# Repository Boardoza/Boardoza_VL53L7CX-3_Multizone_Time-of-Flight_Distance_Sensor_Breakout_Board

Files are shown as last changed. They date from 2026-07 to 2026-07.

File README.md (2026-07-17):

# Boardoza VL53L7CX-3 Time-of-Flight Breakout Board

The **Boardoza VL53L7CX-3 Time-of-Flight Breakout Board** is a compact distance sensing solution built around the **STMicroelectronics VL53L7CX** multizone Time-of-Flight (ToF) sensor. The sensor combines a **940 nm invisible VCSEL emitter** and a **SPAD receiving array** to deliver accurate distance measurements across a configurable **4×4 or 8×8 ranging zone matrix**, providing up to **64 independent zones**.

Designed specifically for **3.3V to 5V powered systems**, this breakout board integrates a low-dropout voltage regulator and level-shifting circuitry for I²C communication and interrupt signaling.This enables direct connection to both 3.3V and 5V microcontroller systems while providing the required operating voltage for the sensor. The board also provides extra control functions such as interrupt output (INT), communication enable control (LPn), and I²C interface reset (RST). Its dual-connector layout also allows multiple boards to be connected in a **cascade connection**, making it easier to use more than one VL53L7CX board on the same I²C bus. Typical applications include **robotics, occupancy detection, gesture recognition, obstacle avoidance, smart appliances, industrial automation, and embedded sensing applications** where compact size and reliable ranging performance are required.

## [Click here to purchase!](https://www.ozdisan.com/p/moduller-870/boardoza-vl53l7cx-3-1577677?s=VL53L7CX-3)

| Front Side | Back Side |
| :---: | :---: |
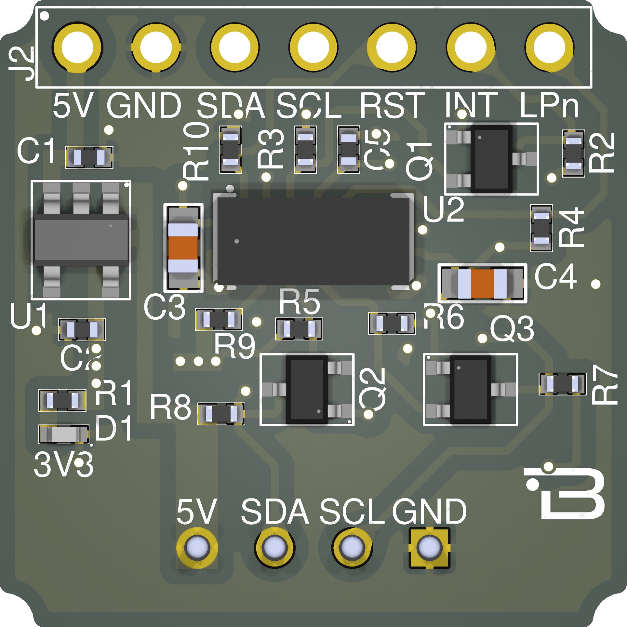
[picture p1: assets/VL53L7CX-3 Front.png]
Front
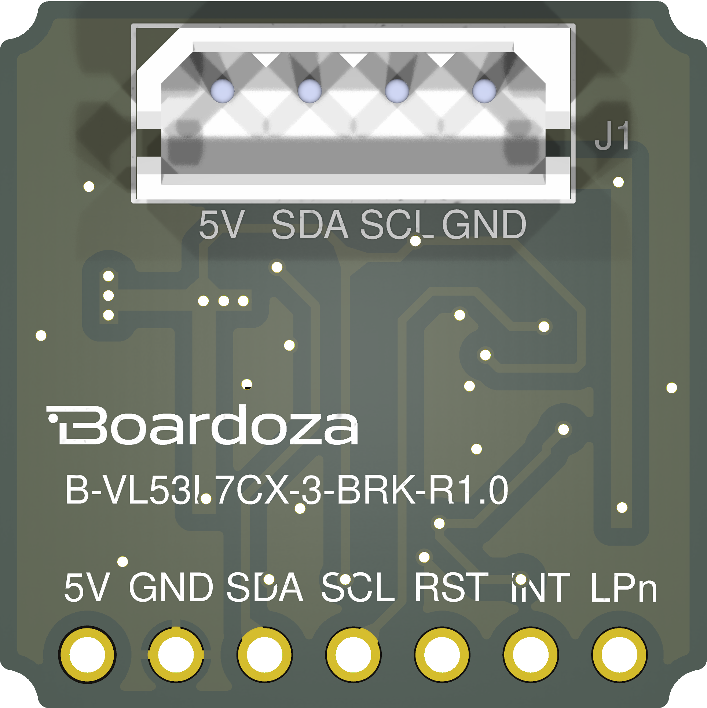
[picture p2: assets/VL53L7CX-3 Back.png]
Back
|  |  |

---

## Key Features

- **Multizone Distance Sensing:** Supports both 4×4 and 8×8 ranging configurations, providing up to 64 independent measurement zones.
- **Ultra-Wide Field of View:** Provides a 60° × 60° square detection FoV with a 90° diagonal field of view.
- **3.3V–5V System Compatible:** Supports a 3.3V to 5V supply input with onboard voltage regulation.
- **Level-Shifted Communication and Interrupt Lines:** SDA, SCL, and INT lines include level shifting for compatibility with 3.3V and 5V microcontroller systems.
- **3.3V Control Signals:** RST and LPn pins operate at 3.3V logic level and should not be driven with 5V signals.
- **Eye-Safe Operation:** Integrated Class 1 invisible 940nm VCSEL (Vertical-Cavity Surface-Emitting Laser) emitter is safe for the eyes and enables safe operation in consumer and industrial products.
- **Multitarget Detection:** Capable of detecting and measuring multiple targets within each ranging zone.
- **Autonomous Low-Power Mode:** Supports autonomous operation with programmable interrupt thresholds for host wake-up applications.
- **Power Status Indicator:** Integrated LED provides visual confirmation of power availability.

---

## Technical Specifications

**Model:** VL53L7CX-3  
**Manufacturer:** Boardoza  
**Manufacturer IC:** STMicroelectronics     
**Function:** Multizone Time-of-Flight (ToF) Distance Sensor  
**Board Supply Voltage:** 3.3V to 5V  
**Onboard Regulation:** 3.3V LDO Regulator  
**Communication Interface:** I²C  
**I²C Address:** 0x52 (8-bit address)  
**Maximum I²C Speed:** 1 Mbit/s  
**Ranging Zones:** 4 × 4 or 8 × 8, up to 64 zones  
**Maximum Sampling Rate:** Up to 60Hz  
**Measurement Range:** 2cm to 350cm per zone  
**Field of View:** 60° × 60° detection FoV, 90° diagonal  
**Emitter Type:** 940nm invisible VCSEL (Vertical-Cavity Surface-Emitting Laser)  
**Detector Type:** SPAD (Single Photon Avalanche Diode) receiving array  
**Safety Classification:** Class 1 Eye-Safe  
**Logic Levels:** 5V compatible on SDA, SCL, and INT; 3.3V on RST and LPn  
**Operating Temperature:** -30°C to +85°C  
**Board Dimensions:** 20mm × 20mm  

---

## Model Comparison

All four boards use the same **STMicroelectronics VL53L7CX multizone Time-of-Flight sensor** and provide the same core ranging capabilities. The main differences between the models are their **supply voltage requirements** and the signals on which **logic-level shifting** is provided.

| Model | Board Supply Input | Onboard 3.3V Regulator | 5V-Compatible Signals | Native 3.3V Signals | Practical Difference | Recommended Use |
| :---: | :---: | :---: | :--- | :--- | --- | --- |
| **VL53L7CX-1** | 3.3V | No | None | SDA, SCL, INT, RST, LPn | The entire board operates directly from 3.3V. No voltage regulation or logic-level shifting is included. All connected signals must remain at 3.3V. | Best for systems in which both the power supply and the microcontroller logic operate at 3.3V. |
| **VL53L7CX-2** | 3.3V to 5V | Yes | SDA, SCL | INT, RST, LPn | The board can be powered from either 3.3V or 5V. The I²C communication lines are level-shifted, allowing SDA and SCL to communicate with both 3.3V and 5V hosts. The control signals remain at 3.3V logic level. | Best when the host uses 5V I²C communication but the INT, RST, and LPn control pins can be handled at 3.3V. |
| **VL53L7CX-3** | 3.3V to 5V | Yes | SDA, SCL, INT | RST, LPn | In addition to the I²C lines, the interrupt output is also level-shifted. This allows the host to receive the INT signal at its own logic voltage. RST and LPn still operate at 3.3V. | Best when both I²C communication and the interrupt signal need to be compatible with a 5V microcontroller.  |
| **VL53L7CX-4** | 3.3V to 5V | Yes | None | SDA, SCL, INT, RST, LPn | The board is powered from 5V, but all communication and control signals remain at native 3.3V logic levels. The connected host must therefore use 3.3V-compatible I/O signals. | Best for systems that provide a 5V power rail but use a 3.3V microcontroller or 3.3V host interface. |

### How to Select the Right Model

* Choose **VL53L7CX-1** when the complete system operates at **3.3V**.
* Choose **VL53L7CX-2** when you need **3.3V–5V compatible I²C communication**, but the control pins can remain at 3.3V.
* Choose **VL53L7CX-3** when both the **I²C lines and the INT output** must be compatible with a 5V host.
* Choose **VL53L7CX-4** when the board will be powered from **3.3V-5V**, but the connected microcontroller uses **3.3V logic**.

> **Important Note:** A board being powered from 5V does not automatically mean that all of its communication and control pins can accept 5V logic signals. Always check the logic-level compatibility of SDA, SCL, INT, RST, and LPn before connecting the board to a host system.

### Common Features of All Four Models

The following features are identical across all four models:

* STMicroelectronics VL53L7CX multizone Time-of-Flight sensor
* 4×4 or 8×8 ranging configurations
* Up to 64 independent measurement zones
* 60° × 60° square detection field of view
* 90° diagonal field of view
* Up to 60Hz ranging frequency
* Multitarget detection within each zone
* I²C communication
* INT, RST, and LPn control functions
* Class 1 eye-safe 940nm VCSEL emitter
* Dual-connector layout for easier multi-board connection

---

## Board Pinout

### ( J1 ) Power & I²C Connector

| Pin Number | Pin Name | Description |
| :---: | :---: | --- |
| 1 | GND | Ground |
| 2 | SCL | I²C Serial Clock |
| 3 | SDA | I²C Serial Data |
| 4 | 5V | Positive Power Supply |

### ( J2 ) Control & I²C Connector

| Pin Number | Pin Name | Description |
| :---: | :---: | --- |
| 1 | 5V | Positive Power Supply |
| 2 | GND | Ground |
| 3 | SDA | I²C Serial Data |
| 4 | SCL | I²C Serial Clock |
| 5 | RST | I²C interface reset input, active high. Toggle from Low to High and back to Low to reset the I²C target interface only. Operates at 3.3V logic level. |
| 6 | INT | Level-shifted interrupt output. Used to notify the host when ranging data or threshold events are available. |
| 7 | LPn | Communication enable input. Pulled up to 3.3V for normal operation; drive Low to disable I²C communication. |

---

## Board Dimensions

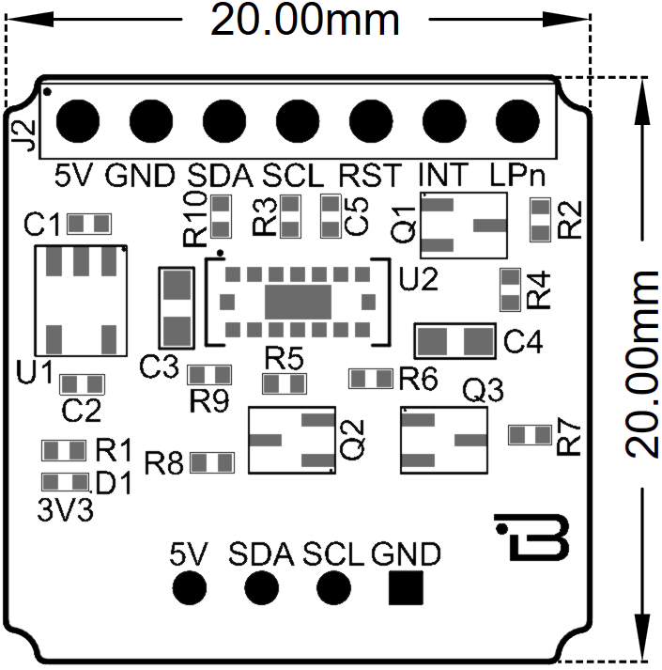
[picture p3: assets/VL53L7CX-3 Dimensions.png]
Board Dimensions


---

## Step Files

[Boardoza VL53L7CX-3.step](./assets/VL53L7CX-3%20Step.step)

---

## Datasheet

[VL53L7CX Datasheet.pdf](./assets/VL53L7CX-3%20Datasheet.pdf)

---

## Version History

- V1.0.0 - Initial Release

---

## Support

- If you have any questions or need support, please contact <support@boardoza.com>

---

## **License**

This repository contains both hardware and software components:

### **Hardware Design**

[][cc-by-sa]

All hardware design files are licensed under [Creative Commons Attribution-ShareAlike 4.0 International License][cc-by-sa].

[cc-by-sa]: http://creativecommons.org/licenses/by-sa/4.0/
[cc-by-sa-shield]: https://img.shields.io/badge/License-CC%20BY--SA%204.0-lightgrey.svg

### **Software/Firmware**

[][bsd]

All software and firmware are licensed under [BSD 3-Clause License][bsd].

[bsd]: https://opensource.org/licenses/BSD-3-Clause
[bsd-shield]: https://img.shields.io/badge/License-BSD%203--Clause-blue.svg

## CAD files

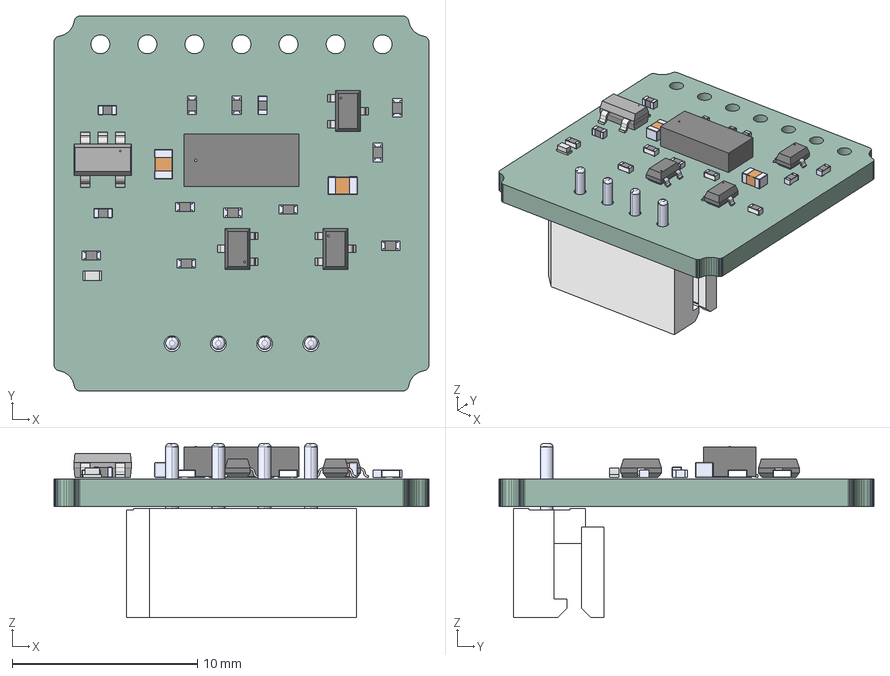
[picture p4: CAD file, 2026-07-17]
assets/VL53L7CX-3 Step.step
20.3 x 20.3 x 9.40 mm
kicad_embedded_76317563F2B0BA1DE970F008EE8390DF x 10
kicad_embedded_AB457CAE88B6C68FE35C010042A3728A x 3
kicad_embedded_D35DFF7FED45AC482DE1625E85CD5640 x 2
kicad_embedded_EA438ED1D3A6F0B84F47F1EFA22486D2 x 3
kicad_embedded_40B7A40821777A177F8D8A57059B139F
kicad_embedded_59573C03DAF8B2D4D31EC39862CB6151
kicad_embedded_75373D3965881231F4D42A25435FEC4F
kicad_embedded_9013914CF1AB6E56C7077459A0893EF9
B-VL53L5CX-3-BRK-R1.0_PCB

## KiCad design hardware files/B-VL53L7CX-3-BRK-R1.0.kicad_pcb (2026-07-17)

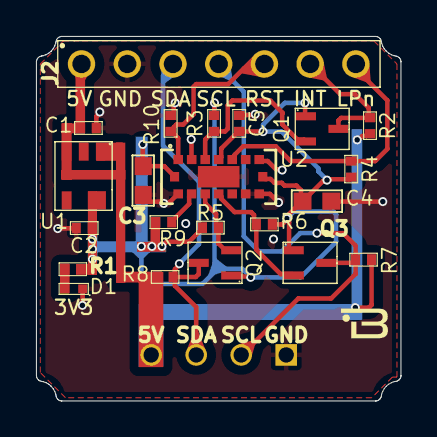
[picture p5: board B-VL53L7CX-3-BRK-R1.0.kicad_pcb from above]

Board: 2 copper layers, 20.3 x 20.3 mm, 23 parts (1 on the bottom side), 13 nets.

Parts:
C1, C2: UMK105CBJ105KV-F; CAP 0402
C3, C4: CL10A475KP8NNNC; CAP 0603
C5: GRM155R71H104KE14D; CAP 0402
D1: 16-213SURC/S530-A3/TR8; LED 0402
J1: L-KLS1-2.50-04-S; 22035045
J2: L-KLS1-207-2.50-1-07-S; PIN Header
Q1, Q2, Q3: BSS138W-7-F; SOT-323
R1: 0402WGJ0201TCE; RES 0402
R2, R3, R4, R9, R10: CQ02WGJ0473TCE; RES 0402
R5, R6, R7, R8: 0402WGF2201TCE; RES 0402
U1: AP2112K-3.3TRG1; SOT-25
U2: VL53L5CXV0GC1; VL53L5CX LGA_CXV0GC1_STM

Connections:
3V3: C2.2, C3.1, C4.1, C5.2, Q1.1, Q2.1, Q3.1, R1.2, R3.2, R4.2, R5.2, R6.2, R9.1, U1.5, U2.A4, U2.B1, U2.B7
5V: C1.2, J1.4, J2.1, R2.2, R7.2, R8.2, U1.1, U1.3
GND: C1.1, C2.1, C3.2, C4.2, C5.1, D1.1, J1.1, J2.2, R10.1, U1.2, U2.17, U2.A2, U2.A6, U2.A7, U2.C1, U2.C6, U2.C7
I2C_RST: J2.5, R10.2, U2.A1
INT: J2.6, Q1.3, R2.1
LPn: J2.7, R4.1, U2.A5
NetD1_2: D1.2, R1.1
NetQ1_2: Q1.2, R3.1, U2.A3
NetQ2_2: Q2.2, R5.1, U2.C3
NetQ3_2: Q3.2, R6.1, U2.C4
NetR9_2: R9.2, U2.C2
SCL: J1.2, J2.4, Q3.3, R7.1
SDA: J1.3, J2.3, Q2.3, R8.1

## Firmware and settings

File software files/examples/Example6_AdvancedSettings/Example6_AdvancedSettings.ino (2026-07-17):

/*
  Read an 8x8 array of distances from the VL53L5CX
  By: Nathan Seidle
  SparkFun Electronics
  Date: October 26, 2021
  License: MIT. See license file for more information but you can
  basically do whatever you want with this code.

  This example shows how to configure:
    Ranging Mode
    Power Mode
    Integration Time
    Sharpener Percent
    Target Order
    Start/Stop Ranging

  Feel like supporting our work? Buy a board from SparkFun!
  https://www.sparkfun.com/products/18642

*/

#include <Wire.h>

#include <SparkFun_VL53L5CX_Library.h> //http://librarymanager/All#SparkFun_VL53L5CX

SparkFun_VL53L5CX myImager;
VL53L5CX_ResultsData measurementData; // Result data class structure, 1356 byes of RAM

int imageResolution = 0; //Used to pretty print output
int imageWidth = 0; //Used to pretty print output

void setup()
{
  Serial.begin(115200);
  delay(1000);
  Serial.println("SparkFun VL53L5CX Imager Example");

  Wire.begin(); //This resets to 100kHz I2C
  Wire.setClock(1000000); //Sensor has max I2C freq of 1MHz

  Serial.println("Initializing sensor board. This can take up to 10s. Please wait.");
  if (myImager.begin() == false)
  {
    Serial.println(F("Sensor not found - check your wiring. Freezing"));
    while (1) ;
  }

  myImager.setResolution(8 * 8); //Enable all 64 pads

  imageResolution = myImager.getResolution(); //Query sensor for current resolution - either 4x4 or 8x8
  imageWidth = sqrt(imageResolution); //Calculate printing width

  // Check if device is alive
  bool response = myImager.isConnected();
  if (response == true)
  {
    Serial.println(F("Sensor is connected."));
  }
  else
  {
    Serial.println(F("Sensor not detected. Freezing."));
    while (1) ;
  }

  // Set the ranging mode
  response = myImager.setRangingMode(SF_VL53L5CX_RANGING_MODE::AUTONOMOUS);
  if (response == true)
  {
    SF_VL53L5CX_RANGING_MODE mode = myImager.getRangingMode();
    switch (mode)
    {
      case SF_VL53L5CX_RANGING_MODE::AUTONOMOUS:
        Serial.println(F("Ranging mode set to autonomous."));
        break;

      case SF_VL53L5CX_RANGING_MODE::CONTINUOUS:
        Serial.println(F("Ranging mode set to continuous."));
        break;

      default:
        Serial.println(F("Error recovering ranging mode."));
        break;
    }
  }
  else
  {
    Serial.println(F("Cannot set ranging mode requested. Freezing..."));
    while (1) ;
  }

  // Set device to sleep mode
  response = myImager.setPowerMode(SF_VL53L5CX_POWER_MODE::SLEEP);
  if (response == true)
  {
    Serial.println(F("Set device to sleep mode."));
  }
  else
  {
    Serial.println(F("Cannot set device to sleep mode. Freezing..."));
    while (1) ;
  }

  // Check if device is actually in sleep mode
  SF_VL53L5CX_POWER_MODE currentPowerMode = myImager.getPowerMode();
  switch (currentPowerMode)
  {
    case SF_VL53L5CX_POWER_MODE::SLEEP:
      Serial.println(F("Shhhh... device is sleeping!"));
      break;

    case SF_VL53L5CX_POWER_MODE::WAKEUP:
      Serial.println(F("Device is awake."));
      break;

    default:
      Serial.println(F("Cannot retrieve device power mode."));
      break;
  }

  Serial.print(F("Waking up device in 5..."));
  delay(1000);
  Serial.print(F(" 4..."));
  delay(1000);
  Serial.print(F(" 3..."));
  delay(1000);
  Serial.print(F(" 2..."));
  delay(1000);
  Serial.println(F(" 1..."));
  delay(1000);

  // Wake up device
  response = myImager.setPowerMode(SF_VL53L5CX_POWER_MODE::WAKEUP);
  if (response == true)
  {
    Serial.println(F("Set device to wakeup mode."));
  }
  else
  {
    Serial.println(F("Cannot wakeup device. Freezing..."));
    while (1) ;
  }

  // Check if device is awake
  currentPowerMode = myImager.getPowerMode();
  switch (currentPowerMode)
  {
    case SF_VL53L5CX_POWER_MODE::SLEEP:
      Serial.println(F("Shhhh... device is sleeping!"));
      break;

    case SF_VL53L5CX_POWER_MODE::WAKEUP:
      Serial.println(F("Device is awake."));
      break;

    default:
      Serial.println(F("Cannot retrieve device power mode."));
      break;
  }

  Serial.print(F("Current integration time: "));
  Serial.print(myImager.getIntegrationTime());
  Serial.println(F("ms"));

  response = myImager.setIntegrationTime(8);
  if (response == true)
  {
    Serial.print(F("Current integration time: "));
    Serial.print(myImager.getIntegrationTime());
    Serial.println(F("ms"));
  }
  else
  {
    Serial.println(F("Cannot set integration time. Freezing..."));
    while (1) ;
  }

  Serial.print(F("Current sharpener value: "));
  Serial.print(myImager.getSharpenerPercent());
  Serial.println(F("%"));

  response = myImager.setSharpenerPercent(19);
  if (response == true)
  {
    Serial.print(F("Current sharpener value: "));
    Serial.print(myImager.getSharpenerPercent());
    Serial.println(F("%"));
  }
  else
  {
    Serial.println(F("Cannot set sharpener value."));
    Serial.println(F("System halted."));
    while (1)
    {
    }
  }

  SF_VL53L5CX_TARGET_ORDER order = myImager.getTargetOrder();
  switch (order)
  {
    case SF_VL53L5CX_TARGET_ORDER::STRONGEST:
      Serial.println(F("Current target order is strongest."));
      break;

    case SF_VL53L5CX_TARGET_ORDER::CLOSEST:
      Serial.println(F("Current target order is closest."));
      break;

    default:
      Serial.println(F("Cannot get target order."));
      break;
  }

  response = myImager.setTargetOrder(SF_VL53L5CX_TARGET_ORDER::CLOSEST);
  if (response == true)
  {
    order = myImager.getTargetOrder();
    switch (order)
    {
      case SF_VL53L5CX_TARGET_ORDER::STRONGEST:
        Serial.println(F("Target order set to strongest."));
        break;

      case SF_VL53L5CX_TARGET_ORDER::CLOSEST:
        Serial.println(F("Target order set to closest."));
        break;

      default:
        break;
    }
  }
  else
  {
    Serial.println(F("Cannot set target order. Freezing..."));
    while (1) ;
  }

  // Start/stop ranging
  response = myImager.startRanging();
  if (response == true)
  {
    Serial.println(F("Ranging has started."));
  }
  else
  {
    Serial.println(F("Cannot start ranging. Freezing..."));
    while (1) ;
  }

  // Uncomment below for testing the STOP ranging command
  /*
    delay(2000);

    // Stop ranging
    response = myImager.stopRanging();
    if (response == true)
    {
    Serial.println(F("Ranging has stopped."));
    }
    else
    {
    Serial.println(F("Cannot stop ranging. Freezing..."));
    while (1) ;
    }
  */

  myImager.startRanging();
}

void loop()
{
  //Poll sensor for new data
  if (myImager.isDataReady() == true)
  {
    if (myImager.getRangingData(&measurementData)) //Read distance data into array
    {
      //The ST library returns the data transposed from zone mapping shown in datasheet
      //Pretty-print data with increasing y, decreasing x to reflect reality
      for (int y = 0 ; y <= imageWidth * (imageWidth - 1) ; y += imageWidth)
      {
        for (int x = imageWidth - 1 ; x >= 0 ; x--)
        {
          Serial.print("\t");
          Serial.print(measurementData.distance_mm[x + y]);
        }
        Serial.println();
      }
      Serial.println();
    }
  }

  delay(5); //Small delay between polling
}

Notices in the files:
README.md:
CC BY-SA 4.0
